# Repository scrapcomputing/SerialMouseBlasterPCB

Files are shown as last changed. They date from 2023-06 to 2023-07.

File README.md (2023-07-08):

# Serial Mouse Blaster (a.k.a. Passive USB to Serial Mouse Adapter)

A PCB used for modding a modern optical USB mouse and converting it into a Serial mouse.

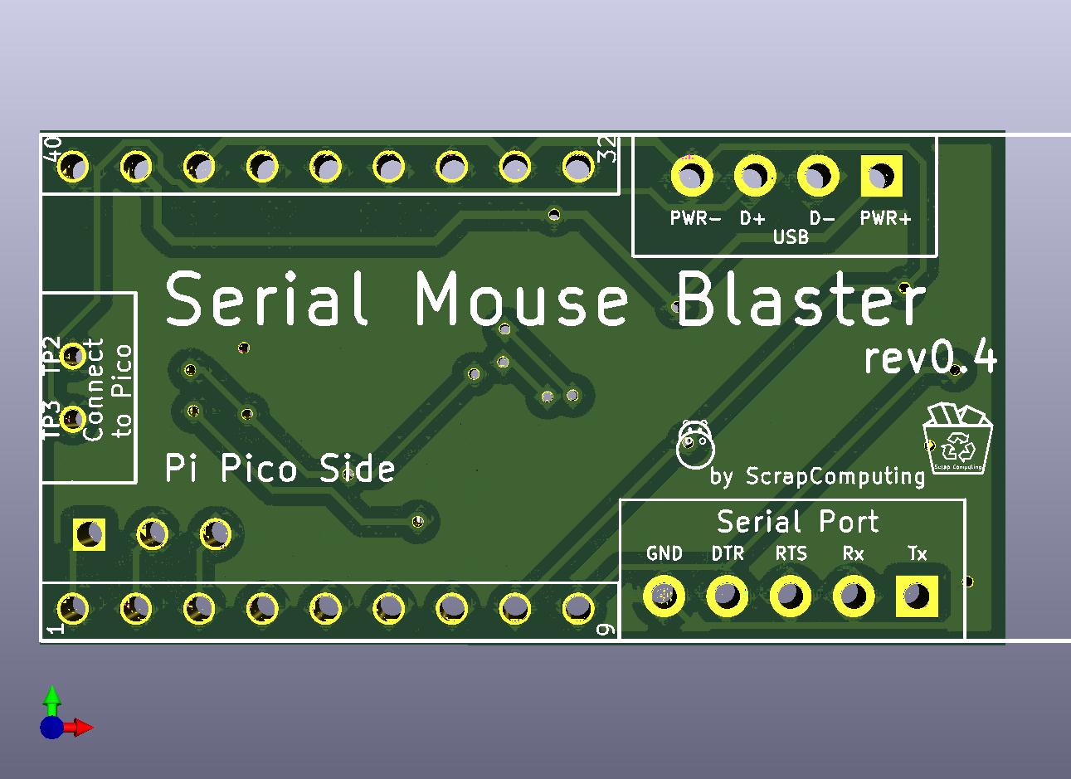
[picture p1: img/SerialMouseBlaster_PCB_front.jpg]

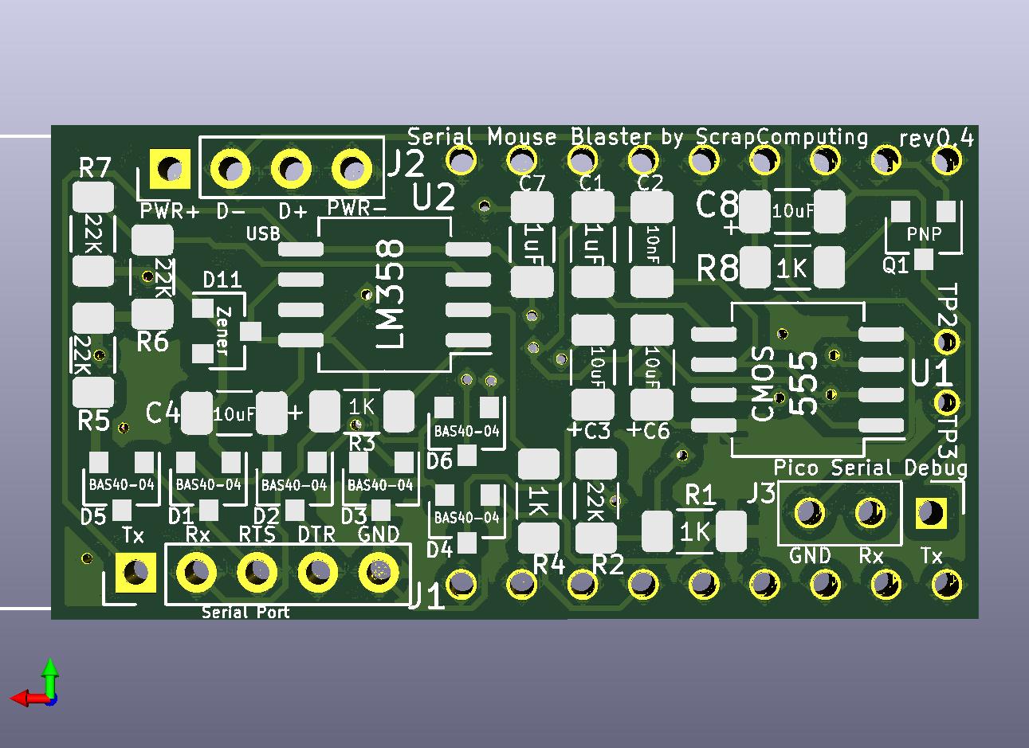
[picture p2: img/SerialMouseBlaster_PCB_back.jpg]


This is based on a Raspberry Pi Pico running the SerialMouseBlaster [firmware](https://github.com/scrapcomputing/SerialMouseBlasterFirmware).

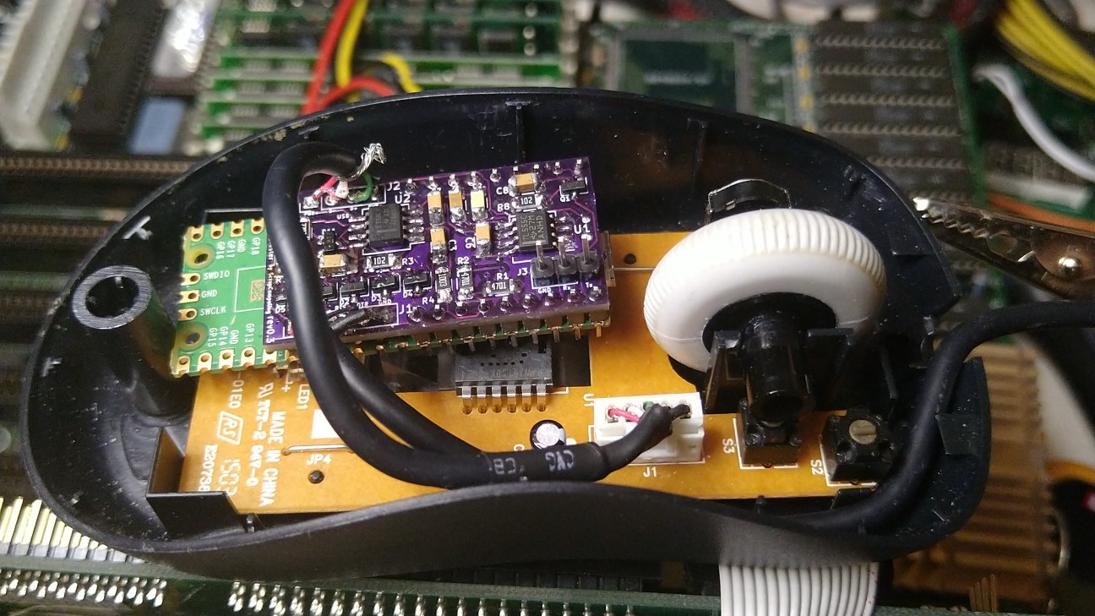
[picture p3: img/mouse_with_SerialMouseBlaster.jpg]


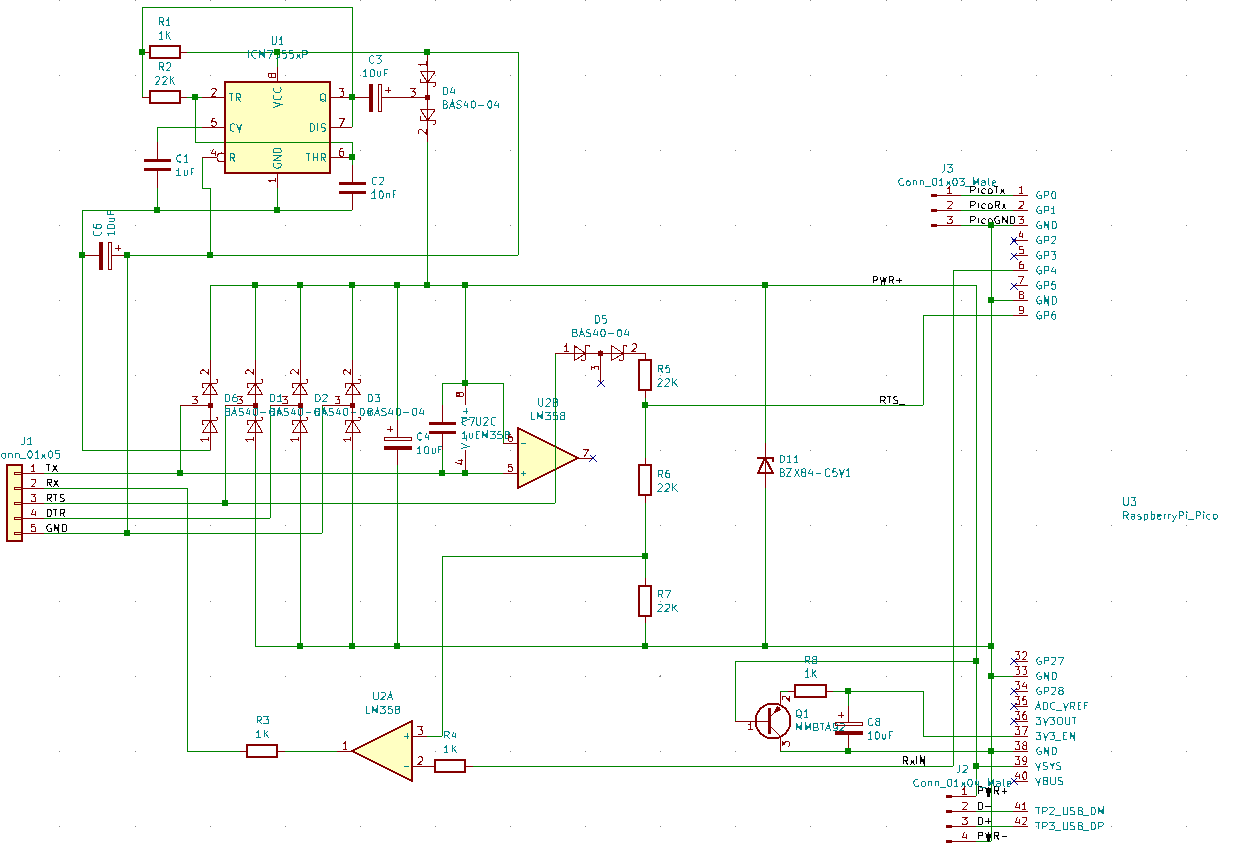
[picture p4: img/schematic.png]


# What does it do

The SerialMouseBlaster has two jobs:
- It extracts as much current as possible from the serial port pins and provides power to a Raspberry Pi Pico running the specifically designed low-power firmware, and to a USB optical mouse with the LED resistor mod for low power consumption.
- It does the necessary level shifting that allows the Pico's GPIOs to talk to the serial port pins that are used by the serial mouse protocol.

The end result is an adapter board that converts a USB optical mouse to a serial one with no external power.

# Which mouse can I use?

Short answer: You have to measure it first, but a relatively modern mouse with a < 5mA consumption on idle should work after the resistor mod.

The serial port provides very little power, up to 15mA in total at 5V.
Currently the Pico consumes about half of it and the rest of the circuitry about another 15-20%. So the we only have about 5mA to spare for the USB mouse. So a good mouse candidate is one that consumes up to 5mA.

The problem though is that most USB optical mice consume much more than this.
But most of the power is usually consumed by the LED (usually red) which illuminates the surface.
Luckily the mouse camera can still work even with a much dimmer LED.
So we can reduce the power consumption by adding a resistor in series with the LED.
A good resistor values is usually around 1K Ohms.
Some mice may even work with higher resistor values, but beyond some value the camera can no longer see the surface and the mouse will not register mouse movement.
So for best results use the largest resistor value you can without affecting the functionality of the mouse.

Some mice already have an SMD resistor in-series with the LED (see image below of the Microsoft Basic Optical Mouse v2.0).
This resistor is usually a very low value.
For a cleaner mod, you can simply replace this resistor with another SMD one of much higher value.

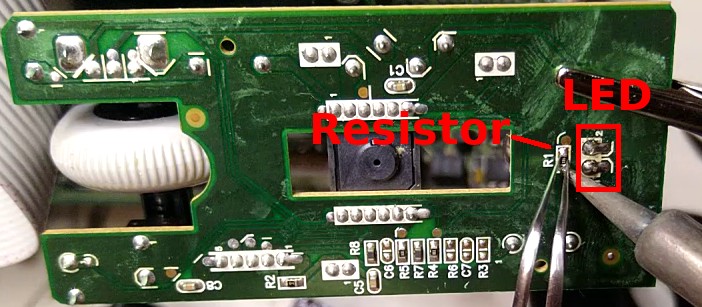
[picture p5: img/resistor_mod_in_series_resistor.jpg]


You can usually tell if a mouse is low-power enough by simply measuring its idle current, without the resistor mod.
If it is under 5mA, then it has a good chance of working well with a mod.
If not, then the chances are that it will consume too much power even with the mod.

Please note that a typical optical USB mouse will consume several times higher power when you move it as the LED becomes a lot brighter than when it is not moving.

## List of mice that work:
 Brand     |  Model                  | Idle Current | Max Current | Mod Resistor |Modded Idle | Modded Max
-----------|-------------------------|--------------|-------------|--------------|------------|-----------
Microsoft  |Basic Optical Mouse v2.0 | 3.5mA        | ~15mA       |  2.2K        | 2.7mA      | 5.4mA
Logitech   | B100                    | 8.4mA        | ~24mA       |  1K          | 6.4mA      | 8.6mA

## List of mice that consume too much power (mostly very early optical mice):
 Brand     |  Model                   | Idle Current | Max Current |
-----------|--------------------------|--------------|-------------|
Dell       | M-UVDEL1                 | 20.7mA       | 59.2mA      |
Apple      | A1152                    | 26.7mA       | 69.7mA      |
Microsoft  | Basic Optical Mouse      | 29.4mA       | 54.3mA      |
Microsoft  | Wheel Mouse Optical 1.1A | 44.1mA       | 61.4mA      |

> **Note**
> Please help me populate these tables. Feel free to reach out or send out a pull request if you measured your mouse and you want to share your numbers.

# How does it work

The serial port does not provide power.
So any device connected to it either needs to be powered externally, or try to use power from the logic output pins. There are 3 output pins: TXD, DTR and RTS. These can usually provide up to about 5mA at 5V.

The SerialMouseBlaster uses power from all three pins. When the mouse driver initializes the serial port, DTR and RTS are high (about +10V), while TXD is low (about -10V). In order to get power from TXD, it uses a 7555 timer chip as a voltage doubler, which outputs positive voltage.

Level-shifting is done with an LM385 Op Amp which consumes only 1.5mA, as opposed to using a MAX3232, which according to my measurements consumed more than 5mA.

# Serial port pinout

Pin | Name | Direction | Description
----|------|-----------|------------
  1 | CD   | IN        | Carrier Detect
  2 | RXD  | IN        | Receive Data
  3 | TXD  | OUT       | Transmit Data
  4 | DTR  | OUT       | Data Terminal Ready
  5 | GND  |           | Ground
  6 | DSR  | IN        | Data Set Ready
  7 | RTS  | OUT       | Request To Send
  8 | CTS  | IN        | Clear To Send
  9 | IR   | IN        | Ring Indicator

```
Female connector looking at the holes:
 -----------------------
|     -------------     |
|     \ 5 4 3 2 1 /     |
| ( )  \ 9 8 7 6 /  ( ) |
|        -------        |
 -----------------------
```

# Videos
- For a discussion/explanation of the circuit: https://www.youtube.com/watch?v=cGvVPzlRPjM
- Assembly video rev0.1: https://www.youtube.com/watch?v=YjD63UplQ3c

# Bill of materials

Gerber files are published in the releases: https://github.com/scrapcomputing/SerialMouseBlasterPCB/releases

The firmware is available here: https://github.com/scrapcomputing/SerialMouseBlasterFirmware

Reference| Quantity| Value| Footprint | Details
---------|---------|------|-----------|--------
C1 C7 |2|1uF|Capacitor SMD|C 1206 3216Metric Pad1.33x1.80mm
C2 |1|10nF|Capacitor SMD|C 1206 3216Metric Pad1.33x1.80mm
C3 C4 C6 C8 |4|10uF|Capacitor SMD|C 1206 3216Metric Pad1.33x1.80mm
D11 |1|BZX84-C5V1|Diode SMD|D SOT-23 ANK
D1 D2 D3 D4 D5 D6 |6|BAS40-04|Package TO SOT SMD|SOT-23
J1 |1|Conn 01x05|Connector PinHeader 2.54mm|PinHeader 1x05 P2.54mm Vertical
J2 |1|Conn 01x04 Male|Connector PinHeader 2.54mm|PinHeader 1x04 P2.54mm Vertical
J3 |1|Conn 01x03 Male|Connector PinHeader 2.54mm|PinHeader 1x03 P2.54mm Vertical
Q1 |1|MMBTA92|Package TO SOT SMD|SOT-23
R1 R3 R4 R8 |4|1K|Resistor SMD|R 1206 3216Metric Pad1.30x1.75mm
R2 R5 R6 R7 |4|22K|Resistor SMD|R 1206 3216Metric Pad1.30x1.75mm
U1 |1|ICM7555xP|Package SO|SO-8 5.3x6.2mm P1.27mm
U2 |1|LM358|Package SO|SO-8 5.3x6.2mm P1.27mm
U3 |1|RaspberryPi Pico| N/A | Raspberry Pi Pico

# Changelist
- Rev0.4 : Handles Tx with positive voltage, adds protection diode for 555.
- Rev0.3 : First SMD only revision.
- Rev0.2 : Initial release. Fixes minor issues of Rev0.1.
- Rev0.1 : Initial revision (not released)

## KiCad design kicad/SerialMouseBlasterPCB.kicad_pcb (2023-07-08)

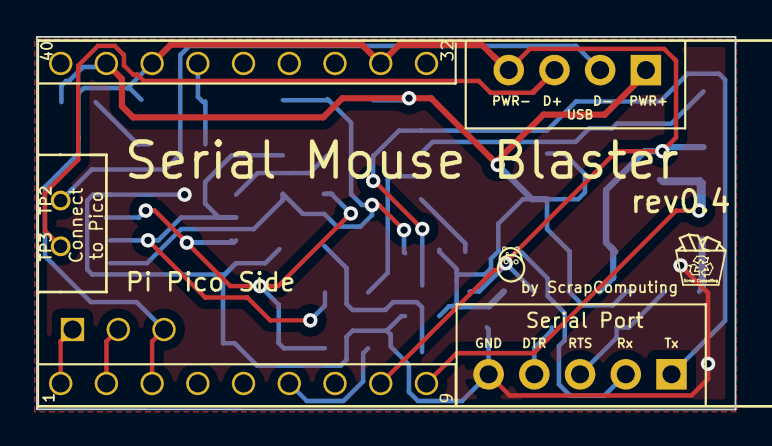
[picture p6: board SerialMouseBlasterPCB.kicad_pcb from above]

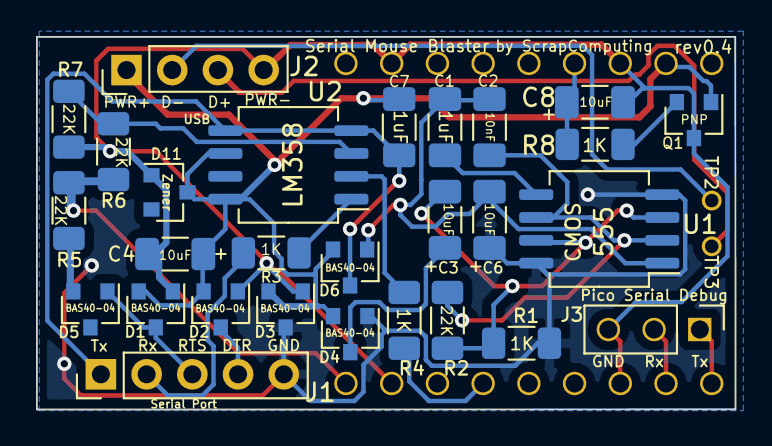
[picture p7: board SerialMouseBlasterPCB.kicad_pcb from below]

Board: 2 copper layers, 38.8 x 20.7 mm, 29 parts (28 on the bottom side), 24 nets.

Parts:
C1, C7: 1uF; C_1206_3216Metric_Pad1.33x1.80mm_HandSolder
C2: 10nF; C_1206_3216Metric_Pad1.33x1.80mm_HandSolder
C3, C4, C6, C8: 10uF; C_1206_3216Metric_Pad1.33x1.80mm_HandSolder
D1, D2, D3, D4, D5, D6: BAS40-04; SOT-23
D11: BZX84-C5V1; D_SOT-23_ANK
J1: Conn_01x05; PinHeader_1x05_P2.54mm_Vertical
J2: Conn_01x04_Male; PinHeader_1x04_P2.54mm_Vertical
J3: Conn_01x03_Male; PinHeader_1x03_P2.54mm_Vertical
Q1: MMBTA92; SOT-23
R1, R3, R4, R8: 1K; R_1206_3216Metric_Pad1.30x1.75mm_HandSolder
R2, R5, R6, R7: 22K; R_1206_3216Metric_Pad1.30x1.75mm_HandSolder
U1: ICM7555xP; SO-8_5.3x6.2mm_P1.27mm
U2: LM358; SO-8_5.3x6.2mm_P1.27mm
U3: RaspberryPi_Pico; raspberry_pi_pico

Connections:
/D+: J2.3, U3.42
/D-: J2.2, U3.41
/DTR: D2.3, J1.4
/GND: C6.1, D3.3, D4.1, J1.5, R1.1, U1.4, U1.8
/PWR+: C4.1, C7.1, D1.2, D2.2, D3.2, D4.2, D6.2, D11.1, J2.1, Q1.1, U2.6, U2.8, U3.39
/PWR-: C4.2, C8.2, D1.1, D2.1, D3.1, D11.2, J2.4, J3.3, Q1.3, R7.2, U3.3, U3.8, U3.33, U3.38
/PicoRx: J3.2, U3.2
/PicoTx: J3.1, U3.1
/RTS: D1.3, D5.1, J1.3
/RTS_: R5.2, R6.1, U3.9
/RX: J1.2, R3.2
/RxIN: R4.1, U3.6
/TX: C7.2, D6.3, J1.1, U2.4, U2.5
unnamed: C1.1, U1.5
unnamed: C1.2, C2.2, C6.2, D6.1, U1.1
unnamed: C2.1, R2.1, U1.2, U1.6
unnamed: C3.1, D4.3
unnamed: C3.2, R1.2, R2.2, U1.3, U1.7
unnamed: C8.1, R8.1, U3.37
unnamed: D5.2, R5.1
unnamed: Q1.2, R8.2
unnamed: R3.1, U2.1
unnamed: R4.2, U2.2
unnamed: R6.2, R7.1, U2.3

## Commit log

2023-06-18 Add link to PCB video
2023-06-18 Improves Readme. Adds mouse power consumption tables.
2023-06-19 Rev 0.3: All components are SMD and the board is much smaller
    - Footprint is much smaller and the gap between the Pico and the PCB can be minimal
    - All SMD components are on one side of the board, which makes them accessible even when the Pico is soldered on
    - Capacitor values have been reduced
    - Pico reset is now fixed with the use of a PNP bleeder transistor
    - All component values are now printed on the PCB
    [SerialMouseBlasterPCB.kicad_pcb, SerialMouseBlasterPCB.sch]
2023-07-08 Rev 0.4: Support positive Tx and add protection diode for 555.
    This also changes some resistor and capacitor values to make it easier to assemble.
    [SerialMouseBlasterPCB.kicad_pcb, SerialMouseBlasterPCB.sch]
